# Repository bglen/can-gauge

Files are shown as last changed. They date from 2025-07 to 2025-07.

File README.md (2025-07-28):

# can-gauge
Electronic CAN-enabled gauge for vehicles.

# Design Requirements

## Mechanical requirements

- The gauge shall be sized to fit 52 mm standard automotive gauge pod mounting dimensions.

- The depth of the enclosure shall not exceed 60 mm to accommodate tight dashboards.

- All connectors shall be rear-facing for clean wiring integration.

## Electrical Requirements

- The gauge shall support an input voltage range of 8 – 16 VDC

- The gauge shall include reverse polarity protection.

- The gauge shall include surge proteciton up to 60V transients, and HBM-level ESD protection for automotive environments

## Display and Interface Requirements

- The gauge shall include a circular display of at least 45 mm diameter.

- The display shall be sunlight readable with at least 800 nits brightness.

- The user shall be able to configure display types: numeric, bar, dial, warning light, etc.

- Display update rate shall be at least 60 Hz for smooth animation

## Communication Requirements

- The gauge shall support CAN 2.0B at a bit rate from 125 kbps to 1 Mbps.

- The gauge shall support importing DBC files or equivalent for message decoding.

- The gauge shall support firmware updates and configuration via CAN or USB.

- The gauge shall include Bluetooth Low Energy (BLE) connectivity for configuration.

## Software Requirements

- The gauge shall support desktop and mobile configuration tools.

- Configuration settings shall be stored in non-volatile memory.

- The gauge shall boot and begin displaying data within 1 second of power-on.

## Enviornmental Requirements

- Operating temperature range: –40°C to +85°C.

- Storage temperature range: –55°C to +105°C.

- The housing shall be resistant to vibration up to 20 g RMS (motorsport-grade).

- The face, enclosure, and electrical connector shall be rated to at least IP65 (dust-tight and water-resistant).

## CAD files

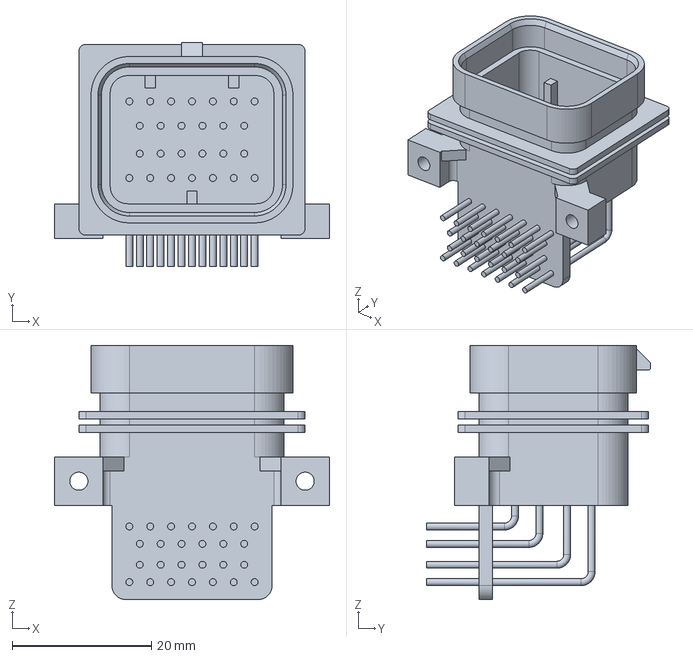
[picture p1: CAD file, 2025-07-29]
hardware/can-gauge/3d_models/amp_superseal_9-6437287-8.step
39.5 x 32.1 x 36.5 mm

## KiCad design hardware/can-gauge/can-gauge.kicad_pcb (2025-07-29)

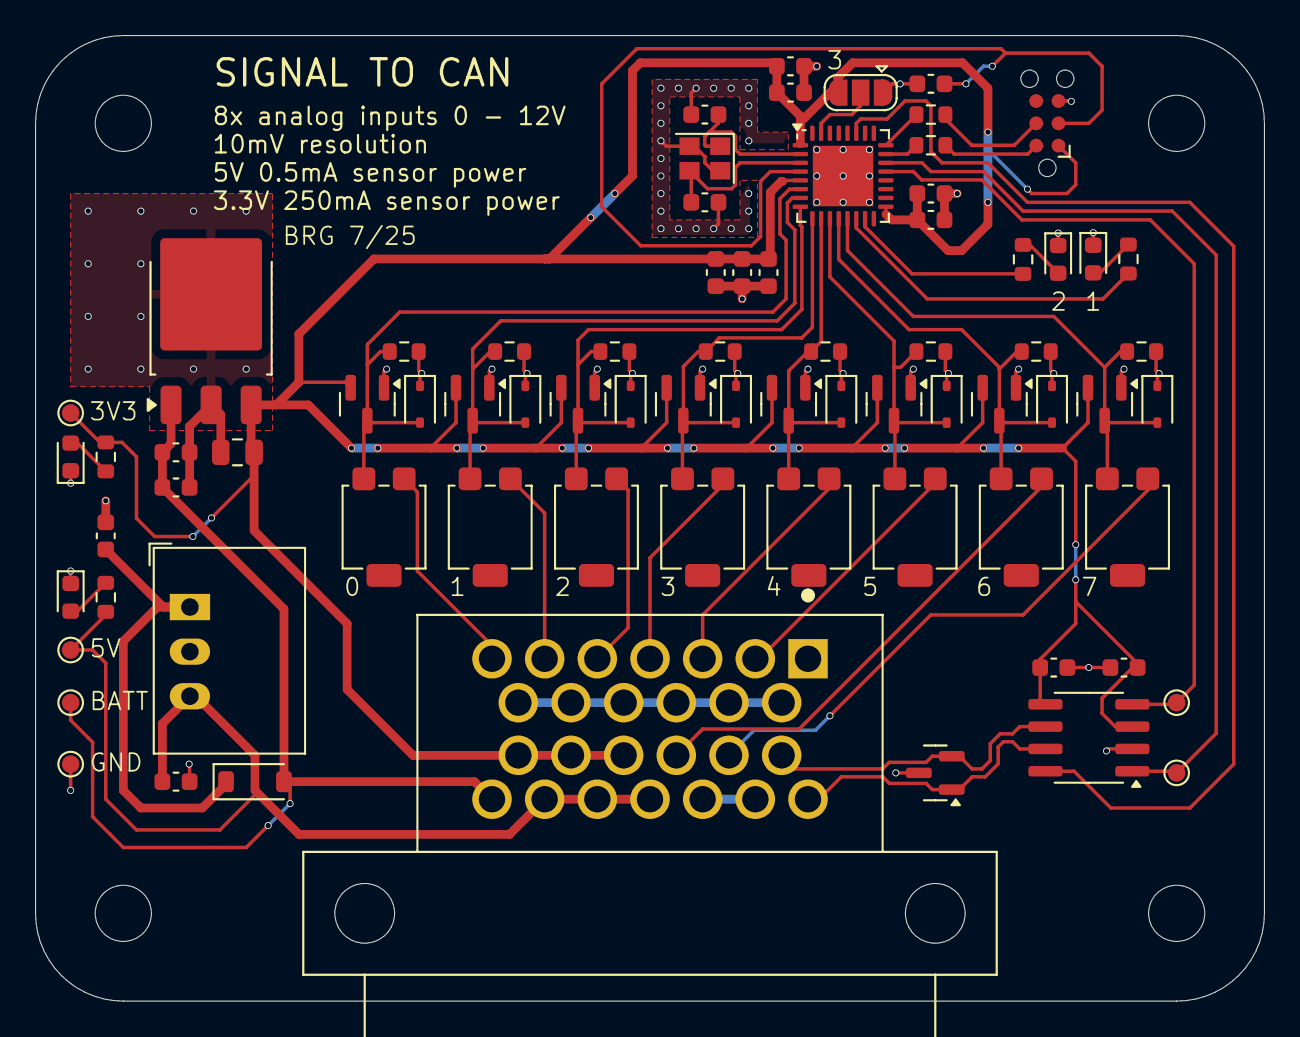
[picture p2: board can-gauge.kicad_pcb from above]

Board: 2 copper layers, 70.0 x 55.0 mm, 79 parts (0 on the bottom side), 40 nets.

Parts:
C1, C2: 4.7uF; C_0603_1608Metric
C3, C4, C5, C6, C12, C14, C15: 0.1uF; C_0603_1608Metric
C7, C9: 12pF; C_0603_1608Metric
C8: 10nF; C_0603_1608Metric
C10, C11: 1uF; C_0603_1608Metric
C13: 22uF; C_0805_2012Metric
C16, C17: 10uF; C_0603_1608Metric
D1, D2, D3, D22: LED; LED_0603_1608Metric
D4: NUP2105L; SOT-23
D5, D6, D7, D8, D13, D14, D15, D16: PESD3V3L1BA; D_SOD-323
D9, D10, D11, D12, D17, D18, D19, D20: BAT54S; SOT-23
D21: CDBW140-G; D_SOD-123
H1, H2, H3, H4: MountingHole; MountingHole_3.2mm_M3
J1: AMP_Superseal_9-6437287-8; TE_9-6437287-8_1
J2: TC2030; Tag-Connect_TC2030-IDC-NL_2x03_P1.27mm_Vertical
JP1: Jumper_3_Open; SolderJumper-3_P1.3mm_Open_RoundedPad1.0x1.5mm
R1, R2: 22; R_0603_1608Metric
R3, R4, R5, R14: 1k; R_0603_1608Metric
R6, R7, R8, R9, R10, R11, R12, R13: 6.8k; R_0603_1608Metric
RV1, RV2, RV3, RV4, RV5, RV6, RV7, RV8: 3314G-1-503E; Potentiometer_Bourns_3314G_Vertical
TP1: POWER_INPUT; TestPoint_Pad_D1.0mm
TP2: GND; TestPoint_Pad_D1.0mm
TP3: 3.3V; TestPoint_Pad_D1.0mm
TP4: CAN_TX; TestPoint_Pad_D1.0mm
TP5: CAN_RX; TestPoint_Pad_D1.0mm
TP6: TestPoint; TestPoint_Pad_D1.0mm
U1: STM32F042K6Ux; QFN-32-1EP_5x5mm_P0.5mm_EP3.45x3.45mm
U2: TLE42744DV33ATMA1; TO-252-3_TabPin2
U3: TCAN3403DRQ1; SOIC-8_3.9x4.9mm_P1.27mm
U4: R-78E5.0-0.5; Converter_DCDC_RECOM_R-78E-0.5_THT
Y1: ECS-160-10-36Q-AES-TR; Crystal_SMD_2520-4Pin_2.5x2.0mm

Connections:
+3V3: C1.1, C2.1, C4.1, C5.1, C6.1, C8.1, C10.1, C13.1, C14.1, C15.1, D9.2 (K), D10.2 (K), D11.2 (K), D12.2 (K), D17.2 (K), D18.2 (K), D19.2 (K), D20.2 (K), J1.17, J1.18, J1.19, J2.1, JP1.3 (B), R5.1, TP3.1, U1.1 (VDD), U1.5 (VDDA), U1.17 (VDDIO2), U2.3 (Q), U3.3 (Vcc), U3.5 (VIO)
+5V: C17.1, J1.23, J1.24, J1.25, R14.1, TP6.1, U4.3 (OUT)
+BATT: C11.2, C12.2, D21.2 (A), J1.26, TP1.1, U2.1 (I)
/3.3V_ANALOG_INPUT_0: D5.2 (A2), D9.3 (COM), R6.1, RV1.3, U1.6 (PA0)
/3.3V_ANALOG_INPUT_1: D6.2 (A2), D10.3 (COM), R7.1, RV2.3, U1.7 (PA1)
/3.3V_ANALOG_INPUT_2: D7.2 (A2), D11.3 (COM), R8.1, RV3.3, U1.8 (PA2)
/3.3V_ANALOG_INPUT_3: D8.2 (A2), D12.3 (COM), R9.1, RV4.3, U1.9 (PA3)
/3.3V_ANALOG_INPUT_4: D13.2 (A2), D17.3 (COM), R10.1, RV5.3, U1.10 (PA4)
/3.3V_ANALOG_INPUT_5: D14.2 (A2), D18.3 (COM), R11.1, RV6.3, U1.11 (PA5)
/3.3V_ANALOG_INPUT_6: D15.2 (A2), D19.3 (COM), R12.1, RV7.3, U1.12 (PA6)
/3.3V_ANALOG_INPUT_7: D16.2 (A2), D20.3 (COM), R13.1, RV8.3, U1.13 (PA7)
/12V_ANALOG_INPUT_0: J1.7, RV1.1
/12V_ANALOG_INPUT_1: J1.6, RV2.1
/12V_ANALOG_INPUT_2: J1.5, RV3.1
/12V_ANALOG_INPUT_3: J1.4, RV4.1
/12V_ANALOG_INPUT_4: J1.3, RV5.1
/12V_ANALOG_INPUT_5: J1.2, RV6.1
/12V_ANALOG_INPUT_6: J1.16, RV7.1
/12V_ANALOG_INPUT_7: J1.15, RV8.1
/CAN_N: D4.2 (K), J1.14, U3.6 (CANL)
/CAN_P: D4.1 (K), J1.20, U3.7 (CANH)
/CAN_RX: TP5.1, U1.21 (PA11), U3.4 (RXD)
/CAN_STANDBY: U1.27 (PB4), U3.8 (STB)
/CAN_TX: TP4.1, U1.22 (PA12), U3.1 (TXD)
/Microcontroller/BOOT0: JP1.2 (C), U1.31 (PF11)
/Microcontroller/LED_STATUS_1: R3.1, U1.14 (PB0)
/Microcontroller/LED_STATUS_2: R4.1, U1.15 (PB1)
/Microcontroller/NRST: C3.1, J2.3, U1.4 (NRST)
/Microcontroller/OSC_IN: C7.2, U1.2 (PF0), Y1.1
/Microcontroller/OSC_OUT: C9.1, U1.3 (PF1), Y1.3
/Microcontroller/SWCLK: R2.2, U1.24 (PA14)
/Microcontroller/SWDIO: R1.2, U1.23 (PA13)
GND: C1.2, C2.2, C3.2, C4.2, C5.2, C6.2, C7.1, C8.2, C9.2, C10.2, C11.1, C12.1, C13.2, C14.2, C15.2, C16.2, C17.2, D1.1 (K), D2.1 (K), D3.1 (K), D4.3 (A), D5.1 (A1), D6.1 (A1), D7.1 (A1), D8.1 (A1), D9.1 (A), D10.1 (A), D11.1 (A), D12.1 (A), D13.1 (A1), D14.1 (A1), D15.1 (A1), D16.1 (A1), D17.1 (A), D18.1 (A), D19.1 (A), D20.1 (A), D22.1 (K), J1.1, J1.8, J1.9, J1.10, J1.11, J1.12, J1.13, J1.21, J1.22, J2.5, JP1.1 (A), R6.2, R7.2, R8.2, R9.2, R10.2, R11.2, R12.2, R13.2, TP2.1, U1.33 (VSS), U2.2 (GND), U3.2 (GND), U4.2 (GND), Y1.2, Y1.4
unnamed: D1.2 (A), R3.2
unnamed: D2.2 (A), R4.2
unnamed: D3.2 (A), R5.2
unnamed: C16.1, D21.1 (K), U4.1 (IN)
unnamed: D22.2 (A), R14.2
unnamed: J2.2, R1.1
unnamed: J2.4, R2.1
